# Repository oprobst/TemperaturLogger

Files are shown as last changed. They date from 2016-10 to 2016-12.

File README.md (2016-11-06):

# TemperaturLogger

Einfacher Temperatur Logger über ATTiny 841 und Knopfzelle.
Gemessen wird über einen TSic 506, wofür die Spannung mittels DCDC Boost auf 5V gesetzt wird.

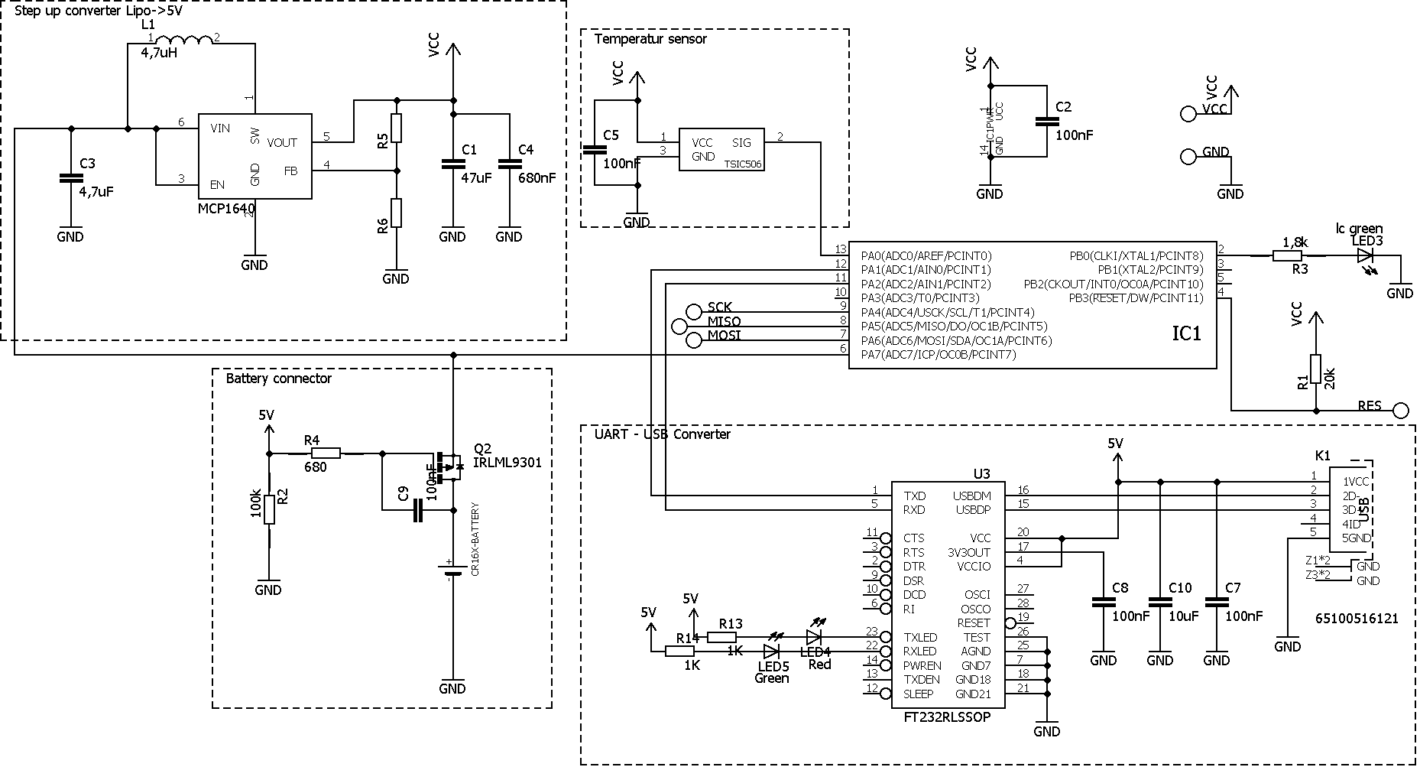
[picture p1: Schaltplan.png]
schaltplan


TODO:
Sobald der Logger an USB angeschlossen wird, kann er per Bootloader neu programmiert werden oder aber die Daten ausgelesen werden.

### Bootloader TinySafeBoot
http://jtxp.org/tech/tinysafeboot.htm
gute Anleitung unter https://ladvien.github.io/robots/tsb/

./tsb tn841 b2a7

tsb COM5:4800 fw TemperaturLogger.hex

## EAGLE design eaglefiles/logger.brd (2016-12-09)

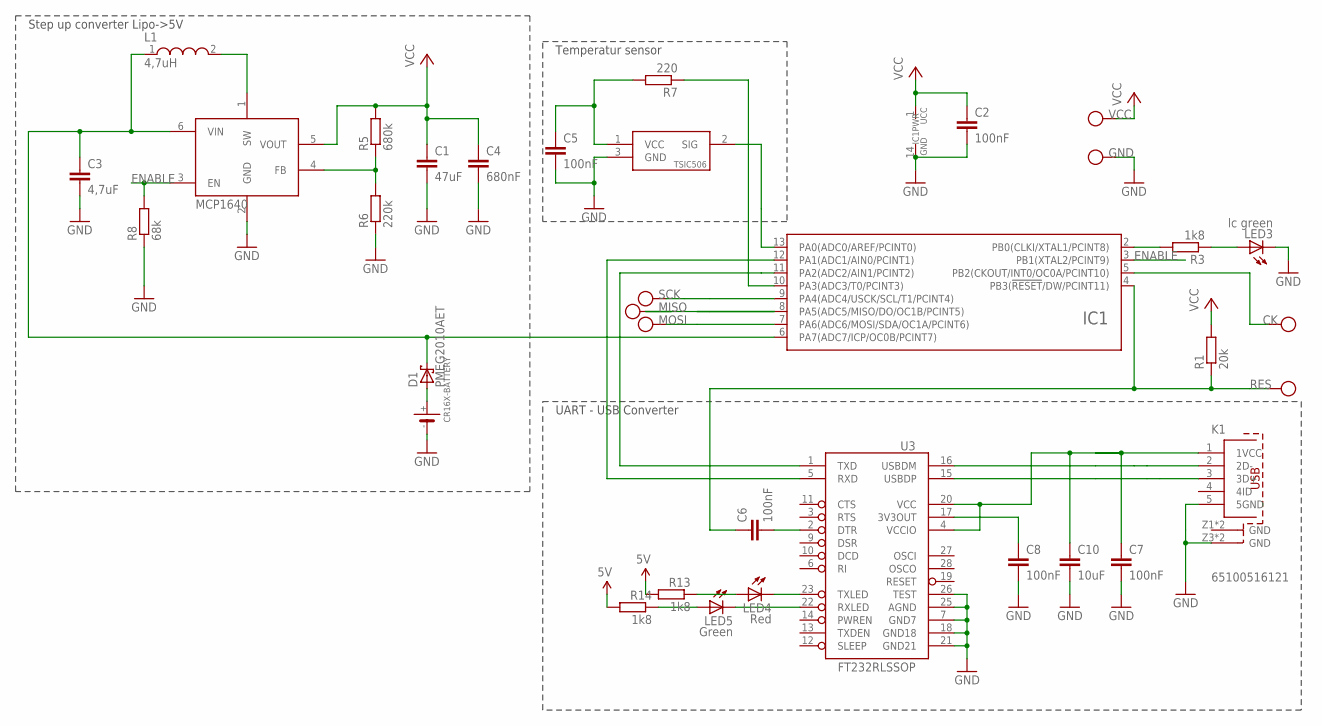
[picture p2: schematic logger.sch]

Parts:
C1: 47uF; C1206
C2, C7: 100nF; C1206
C3: 4,7uF; C1206
C4: 680nF; C0805
C5, C6, C8: 100nF; C0603
C10: 10uF; C1206
D1: PMEG2010AET; SOT23
IC1: ATTINY24/44/84-SSU; SOIC14
K1: 65100516121
L1: 4,7uH; WE-TPC_3816
LED3: lc green; CHIPLED_0603
LED4: Red; CHIPLED_0603
LED5: Green; CHIPLED_0603
R1: 20k; R1206
R3, R13, R14: 1k8; R1206
R5: 680k; R1206
R6: 220k; R1206
R7: 220; R1206
R8: 68k; R1206
U1: MCP1640; SOT23-6
U3: FT232RLSSOP; SSOP28DB
U$1: CR16X-BATTERY; 16MM-BATTERY-HOLDER
U$2: TSIC-506; TO92
U$7, U$8, U$9, U$10, U$11, U$12, U$13: PIN1.27; PIN-1.27

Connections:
CK: IC1.5 (PB2(CKOUT/INT0/OC0A/PCINT10)), U$13.P$1
ENABLE: IC1.3 (PB1(XTAL2/PCINT9)), R8.2, U1.3 (EN)
GND: C1.2, C2.2, C3.2, C4.2, C5.2, C7.2, C8.2, C10.2, IC1.14 (GND), K1.5 (5GND), K1.Z3 (GND), K1.Z4 (GND), LED3.C, R6.1, R8.1, U1.2 (GND), U3.7 (GND7), U3.18 (GND18), U3.21 (GND21), U3.25 (AGND), U3.26 (TEST), U$1.P$1, U$2.3 (GND), U$10.P$1
MISO: IC1.8 (PA5(ADC5/MISO/DO/OC1B/PCINT5)), U$7.P$1
MOSI: IC1.7 (PA6(ADC6/MOSI/SDA/OC1A/PCINT6)), U$11.P$1
unnamed: IC1.11 (PA2(ADC2/AIN1/PCINT2)), U3.1 (TXD)
unnamed: IC1.13 (PA0(ADC0/AREF/PCINT0)), U$2.2 (SIG)
unnamed: C8.1, U3.17 (3V3OUT)
unnamed: LED4.A, R13.1
unnamed: R5.1, R6.2, U1.4 (FB)
unnamed: D1.1 (A), U$1.P$2
unnamed: LED5.A, R14.1
unnamed: C6.2, U3.2 (DTR)
unnamed: IC1.10 (PA3(ADC3/T0/PCINT3)), R7.1
unnamed: C5.1, R7.2, U$2.1 (VCC)
unnamed: LED3.A, R3.1
unnamed: IC1.12 (PA1(ADC1/AIN0/PCINT1)), U3.5 (RXD)
RES: C6.1, IC1.4 (PB3(!RESET!/DW/PCINT11)), R1.1, U$9.P$1
RXLED: LED5.C, U3.22 (RXLED)
SCK: IC1.9 (PA4(ADC4/USCK/SCL/T1/PCINT4)), U$8.P$1
SW: L1.2, U1.1 (SW)
TXLED: LED4.C, U3.23 (TXLED)
USB_D+: K1.3 (3D+), U3.15 (USBDP)
USB_D-: K1.2 (2D-), U3.16 (USBDM)
V+: IC1.2 (PB0(CLKI/XTAL1/PCINT8)), R3.2
VCC: C1.1, C2.1, C4.1, IC1.1 (UCC), R1.2, R5.2, U1.5 (VOUT), U$12.P$1
VSUPPLY: C3.1, D1.3 (C), IC1.6 (PA7(ADC7/ICP/OC0B/PCINT7)), L1.1, U1.6 (VIN)
V_USB: C7.1, C10.1, K1.1 (1VCC), R13.2, R14.2, U3.4 (VCCIO), U3.20 (VCC)

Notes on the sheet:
Step up converter Lipo->5V
Temperatur sensor
UART - USB Converter

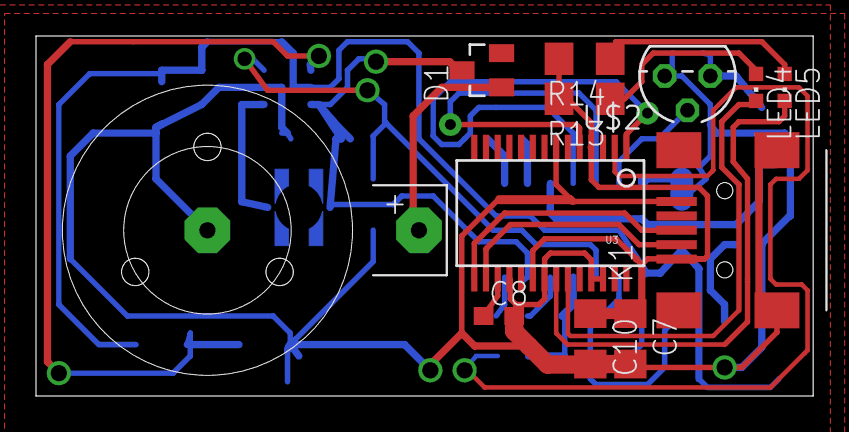
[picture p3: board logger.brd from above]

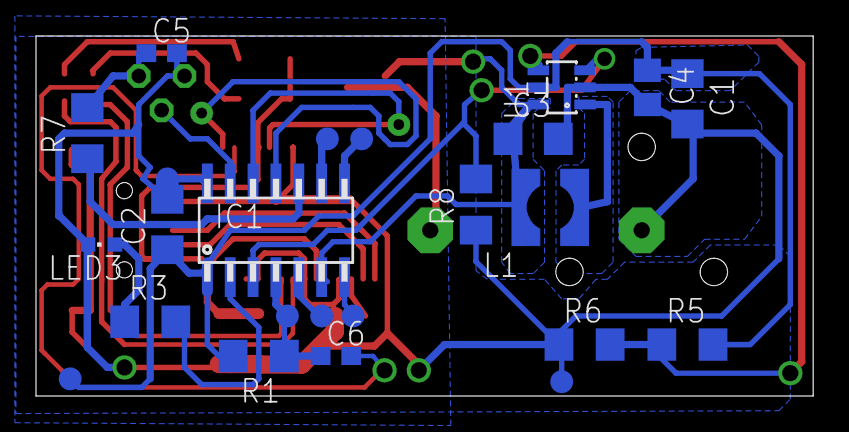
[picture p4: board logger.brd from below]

Board: 2 copper layers, 43.2 x 20.0 mm, 35 parts (23 on the bottom side), 28 nets.

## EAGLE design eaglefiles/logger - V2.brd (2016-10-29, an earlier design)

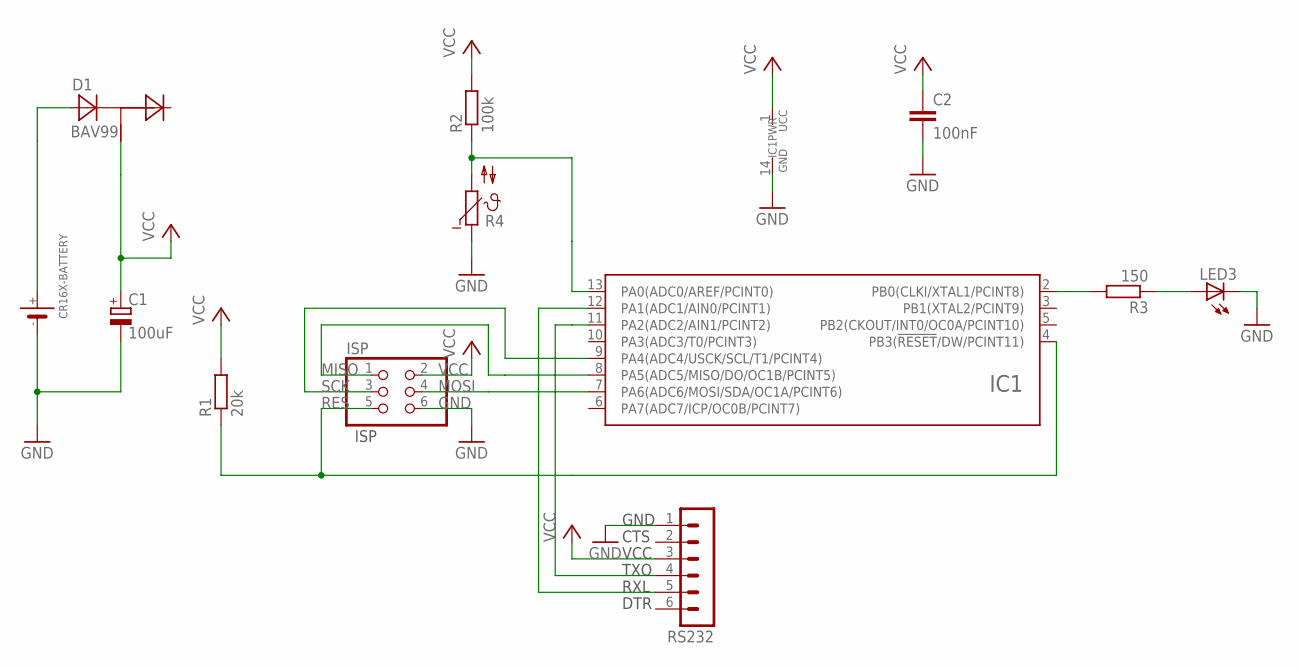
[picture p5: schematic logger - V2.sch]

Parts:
C1: 100uF; 153CLV-0505
C2: 100nF; C1206K
D1: BAV99; SOT-23
IC1: ATTINY24/44/84-SSU; SOIC14
ISP: PINHD-2X3; 2X03
LED3: LED3MM
R1: 20k; R1206
R2: 100k; R1206
R3: 150; R1206
R4: NTC640; P640
RS232: MA06-1
U$1: CR16X-BATTERY; 16MM-BATTERY-HOLDER

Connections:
D1: D1.3 (A), U$1.P$2
GND: C1.-, C2.2, IC1.14 (GND), ISP.6, LED3.K (C), R4.1, RS232.1, U$1.P$1
MISO: IC1.8 (PA5(ADC5/MISO/DO/OC1B/PCINT5)), ISP.1
MOSI: IC1.7 (PA6(ADC6/MOSI/SDA/OC1A/PCINT6)), ISP.4
unnamed: IC1.11 (PA2(ADC2/AIN1/PCINT2)), RS232.4
unnamed: IC1.13 (PA0(ADC0/AREF/PCINT0)), R2.1, R4.2
unnamed: LED3.A, R3.1
unnamed: IC1.12 (PA1(ADC1/AIN0/PCINT1)), RS232.5
RES: IC1.4 (PB3(!RESET!/DW/PCINT11)), ISP.5, R1.1
SCK: IC1.9 (PA4(ADC4/USCK/SCL/T1/PCINT4)), ISP.3
V+: IC1.2 (PB0(CLKI/XTAL1/PCINT8)), R3.2
VCC: C1.+, C2.1, D1.1 (M), IC1.1 (UCC), ISP.2, R1.2, R2.2, RS232.3

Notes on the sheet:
DTR
RXL
TXO
VCC
CTS
GND
ISP

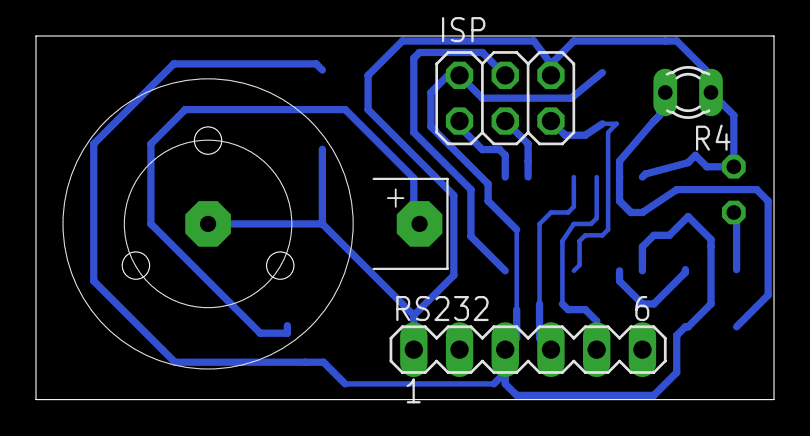
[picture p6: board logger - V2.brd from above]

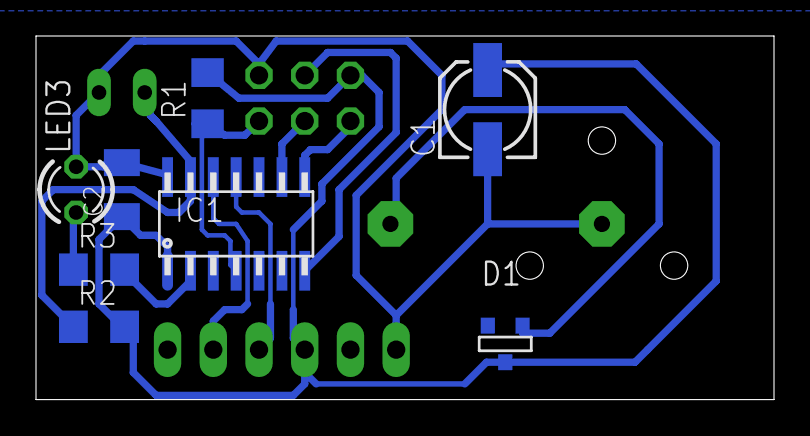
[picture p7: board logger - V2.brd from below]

Board: 2 copper layers, 41.0 x 20.2 mm, 12 parts (8 on the bottom side), 12 nets.

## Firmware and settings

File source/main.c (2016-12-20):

#include "main.h"

volatile uint32_t secondsSinceLastMeasurement = 0;
int32_t temperature = 0;

ISR (TIMER1_COMPA_vect) {
	secondsSinceLastMeasurement++;
}

/************************************************************************/
/* Main                                                                 */
/************************************************************************/
int main( void )
{
	//Outputs:
	//PB0: LED
	//PB1: 5V supply power enable
	DDRB |= (1 << PB0 | 1 << PB1);
	//PA3: Power up supply sensor
	DDRA |= (1 << PA3);

//test
	//Clock on PB2
	//CLKCR |= (1 << CKOUTC);	
	//set_start_temperature(5);
	//set_end_temperature(30);
	//set_resolution(1);
	//set_intervall(180);
//endoftest
	
	init_adc();
	init_interrupts ();
	init_converter();
	TSIC_INIT();	// Init TSIC Temperatursensor
	
	sei();
	_delay_ms(1000);
	
	uint16_t supplyVolt = measure_supply_voltage();
	
	//measure_mode(); //outcomment me to debug on pc
	
	if (supplyVolt < 4500 && supplyVolt > 1000){
		// Set UART pins to 0, to prevent reverse voltage from ft232 VCC pin (~ 1V if RX/TX = Hi)
		DDRA |= (1 << PA1 | 1 << PA2);
		PORTA |= (0 << PA1  | 0 << PA2);
		measure_mode();
		} else{
		uart_init();
		output_mode ();
	}
}



void power_down(){
	set_sleep_mode(SLEEP_MODE_PWR_DOWN);
	sleep_enable();
	sleep_cpu();
	sleep_disable();
}

void idle(){
	ACSR1A |= ((1 << ACD1) ); //disable ac
	ACSR1A |= ((1 << ACD1) ); //disable ac
	set_sleep_mode(SLEEP_MODE_IDLE);
	sleep_enable();
	sleep_cpu();
	sleep_disable();
}


void measure_mode(){
	for (uint8_t i = 0; i < 26; i++){
		PORTB ^= (1<<PB0);
		_delay_ms(200);
	}
	while(1) {
		
		if (secondsSinceLastMeasurement >= get_interval()){
			POWER_HI
			_delay_ms(2);
			PORTB ^= (1<<PB0);
			ACSR1A |= ((0 << ACD1) ); //enable ac
			ACSR0A |= ((0 << ACD1) ); //enable ac
			uint16_t temp;
			getTSicTemp(&temp);
			uint32_t write = to_units(temp);
			write_next_value(write);
			POWER_LO
			PORTB ^= (1<<PB0);
			
			if (is_buffer_full()){
				while(1)
				{
					power_down();
				}
			}
			secondsSinceLastMeasurement = 0;
			idle ();
		}
		
	}
}

void output_mode (){
	PORTB ^= (1<<PB0);
	//uart_transmit_string("\n\rTEMPERATURE LOGGER\n\r");
	//uart_transmit_string("\n\r USB MODE \n\r");
	print_help();
	while(1)
	{
		char command = uart_receive();
		if (command == 'T'){
			_delay_ms(0);
			if (getTSicTemp(&temperature)){ //turn the TSIC-Sensor ON -> messure -> OFF
				
				uart_transmit_string("T");
				uart_transmit_integer(temperature);
				uart_transmit_string("t");
			}
			
			} else if (command == 'C'){
			show_configuration();
			} else if (command == 'M'){
			
			uart_transmit_string("Sending EEPROM! \n\r");
			
			uint16_t nextValue = 0;
			while(! is_buffer_full()){
				nextValue = read_next_value();
				uint16_t output = to_temperatur(nextValue);
				uart_transmit_string(",");
				uart_transmit_integer(output);
			}
			uart_transmit_string(" \n\r End of EEPROM... \n\r");
			eeprom_reset_current_address();
			} else if (command == 'i'){
			set_intervall(read_config_value());
			show_configuration();
			} else if (command == 'e'){
			set_end_temperature(read_config_value());
			show_configuration();
			} else if (command == 's'){			
			set_start_temperature(read_config_value());
			show_configuration();
			} else if (command == 'r'){
			set_resolution(read_config_value());
			show_configuration();
			} else if (command == 'c'){
			clear();
			show_configuration();
			} else if (command == 'p'){
			if (get_protected_mode() == 1){
				set_protected_mode(0);
			} else{
				set_protected_mode(1);
			}
			show_configuration();
			} else {
			uart_transmit_string("Unknown \n\r");
			print_help();
		}
		
	}
}


void print_help(){
	uart_transmit_string("Valid commands: \n\r");
	uart_transmit_string(" T  => One measurement\n\r");
	uart_transmit_string(" C  => Config\n\r");
	uart_transmit_string(" M  => Memory\n\r");
	uart_transmit_string(" ixxx  => intervall in sec.\n\r");
	uart_transmit_string(" sxxx  => min C\n\r");
	uart_transmit_string(" exxx  => max C\n\r");
	uart_transmit_string(" rxxx  => res (001 or 002) \n\r");
	uart_transmit_string(" p  => protected \n\r");
}

void show_configuration(){
	uart_transmit_string("\n\r Resolution: ");
	uart_transmit_integer(get_resolution());
	uart_transmit_string("\n\r From range: ");
	uart_transmit_integer(get_start_temperature());
	uart_transmit_string("\n\r To range: ");
	uart_transmit_integer(get_end_temperature());
	uart_transmit_string("\n\r Interval : ");
	uart_transmit_integer(get_interval());
	uart_transmit_string(" sec.\n\r ");
	uart_transmit_string("\n\r protected: ");
	uart_transmit_integer(get_protected_mode());
	uart_transmit_string(" mV\n\r ");
	uart_transmit_string("\n\r Voltage : ");
	uart_transmit_integer(measure_supply_voltage());
	uart_transmit_string(" mV\n\r ");
	if (getTSicTemp(&temperature)){ 
	    uart_transmit_string("Temperature:");
		uart_transmit_integer(temperature);
		uart_transmit_string("\n\r");
	}
}
void init_interrupts (){
	//every second
	
	TCCR1B |= (1 << WGM12); // CTC Modus
	TIMSK1 |= (1<<OCIE1A); // Allow interrupt
	TCCR1B |= (0<<CS12) | (1<<CS11) | (1<<CS10); // Prescaler 64
	OCR1A = 15624;
	
}

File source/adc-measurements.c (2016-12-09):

#include <avr/io.h>
#include <stdint.h>
#include <util/delay.h>

#include "adc-measurements.h"


uint16_t readADCsamples( uint8_t nsamples );
uint16_t readSingleADC(void);

void init_adc (){

	//ADC enabled, prescaler
	ADCSRA =
	(1 << ADEN)  |
	(0 << ADPS2) |
	(1 << ADPS1) |
	(1 << ADPS0);
		
}


uint32_t measure_temperature_sensor (volatile uint16_t supplyVoltage) {
	ADMUXB=
	(0 << REFS2) |
	(0 << REFS1) |
	(0 << REFS0) |
	(0 << GSEL1) |
	(0 << GSEL0);


	ADMUXA =
	(0 << MUX3)  |
	(0 << MUX2)  |
	(0 << MUX1)  |
	(0 << MUX0);
	
	uint16_t measure = readADCsamples(5);
	return (((measure / 1023.0) * supplyVoltage / 1000.0) - 2.7315) * 10000.0;
}



uint16_t measure_internal_temperature (volatile uint16_t supplyVoltage) {
	ADMUXB=
	(0 << REFS2) |
	(0 << REFS1) |
	(0 << REFS0) |
	(0 << GSEL1) |
	(0 << GSEL0);


	ADMUXA =
	(1 << MUX3)  |
	(1 << MUX2)  |
	(1 << MUX1)  |
	(1 << MUX0);
	
	uint16_t measure = readADCsamples(5);
	return (((measure / 1023.0) * supplyVoltage / 1000.0) - 2.7315) * 100.0;
}


// measure supply voltage in mV
uint16_t measure_supply_voltage(void)
{
	ADMUXB= (0 << REFS2)|(0 << REFS1)|(0 << REFS0); //VCC as reference
	ADMUXA= ((1 << MUX3)|(1 << MUX2)|(0 << MUX1)|(1 << MUX0)); // measure internal 1.1V

	_delay_us(500);

	uint32_t sum = 0;
	uint8_t nsamples = 3;
	_delay_us(500);
	for (uint8_t i = 0; i < nsamples; ++i ) {
		ADCSRA |= (1 << ADSC);        // start conversion
		while (ADCSRA & (1 << ADSC)); // wait to finish
		sum += (1100UL*1023/ADC);     // AVcc = Vbg/ADC*1023 = 1.1V*1023/ADC
	}
	
	
	//return (uint16_t)( sum / nsamples );
	
	uint16_t vcc =(uint16_t)( sum / nsamples );
	ADMUXA= ((0 << MUX3)|(1 << MUX2)|(1 << MUX1)|(1 << MUX0)); // measure ADC7 = battery voltage
	
	sum = 0;
	nsamples = 3;
	_delay_us(500);
	for (uint8_t i = 0; i < nsamples; ++i ) {
		ADCSRA |= (1 << ADSC);        // start conversion
		while (ADCSRA & (1 << ADSC)); // wait to finish
		sum +=  (((double)vcc)/1023.0*ADC);     // AVcc = Vbg/ADC*1023 = 1.1V*1023/ADC
	}
	return (uint16_t)( sum / nsamples );
	
	
}

uint16_t readADCsamples( uint8_t nsamples )
{
	uint32_t sum = 0;
	_delay_us(500);
	for (uint8_t i = 0; i < nsamples; ++i ) {
		sum += readSingleADC( );
	}
	
	return (uint16_t)( sum / nsamples );
}





uint16_t readSingleADC(void)
{
	
	uint8_t adc_lobyte; // to hold the low byte of the ADC register (ADCL)
	uint16_t raw_adc;
	
	ADCSRA |= (1 << ADSC);         // start ADC measurement
	while (ADCSRA & (1 << ADSC) ); // wait till conversion complete

	// for 10-bit resolution:
	adc_lobyte = ADCL; // get the sample value from ADCL
	raw_adc = ADCH<<8 | adc_lobyte;   // add lobyte and hibyte

	return raw_adc;
}

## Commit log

2016-10-29 Initial check in of first tests
    [logger - V2.brd, logger - V2.sch, logger.brd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]
2016-11-03 UART-USB Adapter and TSIC-506 added
    [logger.brd, logger.sch]
2016-11-04 Added ctr for reset
    [logger.brd, logger.sch]
2016-11-04 First temperatur log implementation
2016-11-05 Extracted extra files for adc measurement
2016-11-05 Externalized uart communication to own file
2016-11-05 Added timer interrupts
2016-11-12 Corrected direction of mosfet
    [logger.brd, logger.sch]
2016-11-12 Corrected direction of mosfet & copied lib for tsic
    [logger.brd, logger.sch]
2016-11-12 Added diode for 5V usb port
    [logger.brd, logger.sch]
2016-11-12 Added option to trigger 5V supply voltage only on demand
    [logger.brd, logger.sch]
2016-11-12 Adjusted reverse voltage of uart -> FT232 VCC
    [logger.brd, logger.sch]
2016-11-12 Adjusted uart pins to 0 in measure mode, this time really... ;-)
2016-11-15 Fixed failure in schematic: TX and RX mixed up...
    [logger.brd, logger.sch]
2016-11-15 First include of temperature sensor, additional main.h
2016-11-17 Fixed wrong signal
    [logger.brd, logger.sch]
2016-11-17 Added mean temperature curve
2016-12-08 Replaced mosfet by diode
    [logger.brd, logger.sch]
2016-12-08 Mainly power management
2016-12-09 Adjusted to TSIC 516, added option to configure per uart
2016-12-20 added protected mode (still bugy)
    [main.c]

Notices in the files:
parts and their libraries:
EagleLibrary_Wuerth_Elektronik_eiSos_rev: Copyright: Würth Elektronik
